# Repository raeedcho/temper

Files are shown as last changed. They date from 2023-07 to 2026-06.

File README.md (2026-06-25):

# temper

This is a split, wireless-only mechanical keyboard fashioned after the [chocofi keyboard](https://github.com/pashutk/chocofi). It started as a simple modification of the original chocofi PCBs to include battery pads and power switches for wireless use, but in the end, I thought there were enough changes to warrant giving it a separate designation. However, this design remains compatible with chocofi cases and plates.

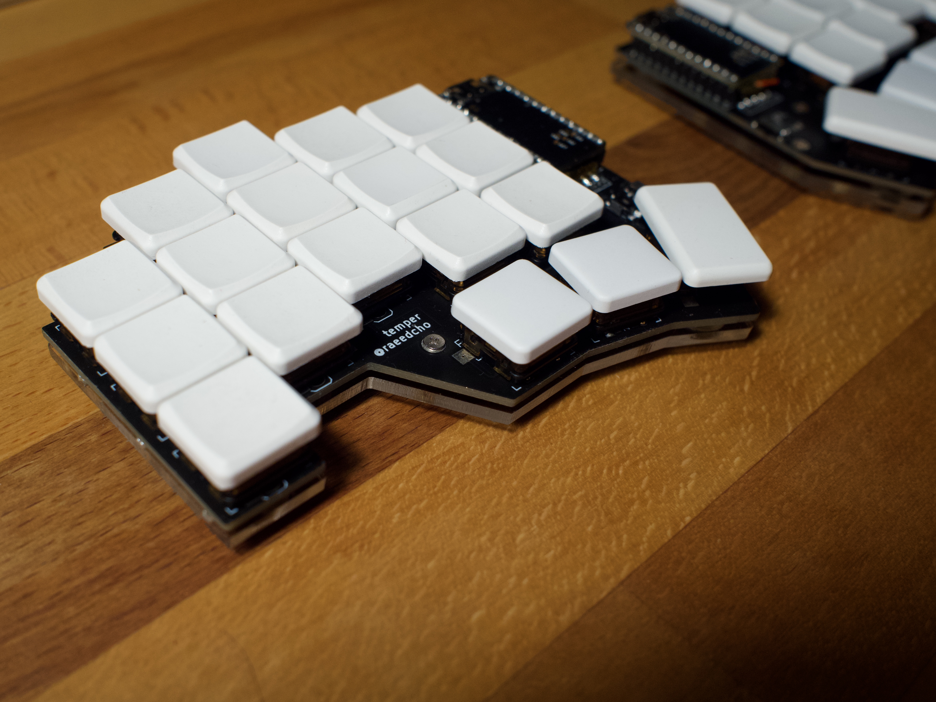
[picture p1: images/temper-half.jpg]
temper keyboard


## Features

- 36-key split keyboard with 3 rows x 5 columns + 3 thumb keys per half 
- Kailh choc spacing
- Sweep-like column stagger (with pinky columns 2 mm lower, like chocofi) with Corne-like thumb cluster
- Reversible PCB (so one design can be used for both halves)
- Kailh choc hotswap sockets
- Intended to be used with [nice!nano](https://nicekeyboards.com/nice-nano)
- Uses 7-pin SPDT power switch and includes pads for battery on keyboard shield PCB
- Support for [nice!view](https://nicekeyboards.com/nice-view)
- Compatible with chocofi cases and plates

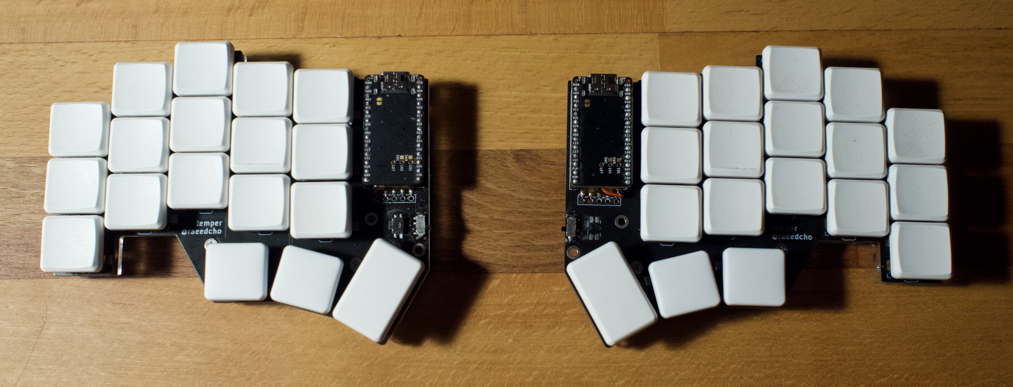
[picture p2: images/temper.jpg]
temper keyboard


## List of changes from original chocofi

- Add power switch
- Add solder pads for battery under ProMicro footprint
- Add footprint for a nice!view screen
- Switch out diode footprints for ones that have solder pads on both sides
- Switch ProMicro footprint for one that uses solder jumpers for cleaner design
- Remove TRRS jack
- Change reset switch out for one I could easily source from [Typeractive](https://www.typeractive.xyz)
- Rework KiCAD schematic for more pleasant development

## Bill of Materials

- 2x PCB (gerber files in [releases](https://github.com/raeedcho/temper/releases))
- 2x nice!nanos
- 2x LiPo batteries (see nice!nano documentation for suggestions)
- 2x Alps miniature SPDT switches
- 2x Panasonic miniature momentary button switches 
- 36x Kailh choc v1 switches
- 36x Kailh choc hotswap sockets
- 36x Choc v1 keycaps
- 36x 1N4148W SMD diodes
- (Technically optional but highly recommended) MCU socket:
  - 4x Mill-Max 310 series machine sockets
  - 48x Mill-Max pins for socketing microcontrollers
- (Optional) Minimal back plate case:
  - 2x 3mm acrylic back plate (SVG file for laser cutting in [case folder](case/temper-bottomplate.svg))
  - 10x M2 4 or 5mm brass standoffs (I used 5mm, but some users have said that 4mm fits better)
  - 20x M2 3mm screws
- (Optional) 2x FR-4 switch plate (goes well with the back plate--gerber files in [releases](https://github.com/raeedcho/temper/releases))
- (Optional) 2x nice!view screens

## Assembly

Assembly of this keyboard requires soldering the jumpers on the front-side of each PCB (underneath the microcontrollers). Past this, the assembly of this keyboard is similar to that of many other split wireless keyboards--there are many guides online to help. In case it helps with assembly, there's a screenshot of the PCB schematic in the somewhat incomplete [PCB folder readme](https://github.com/raeedcho/temper/tree/main/pcb).

Briefly, the full list of steps includes:

- Solder the jumpers underneath where the microcontrollers and battery would go (on PCB front). It's best to do this step first, since it's easiest when there are no other components on the board.
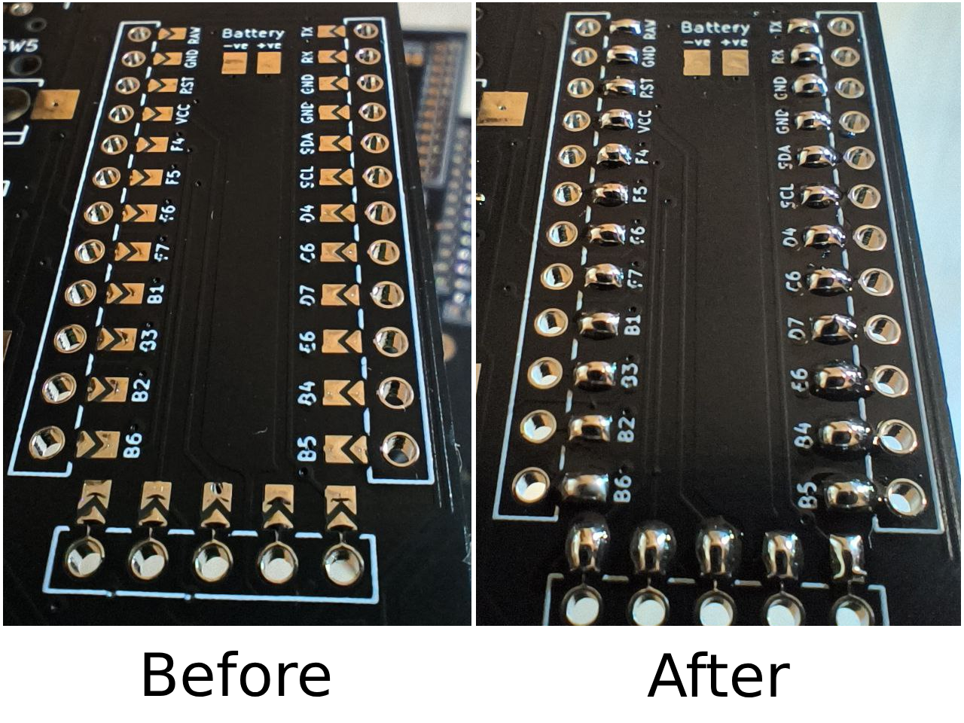
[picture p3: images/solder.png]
Soldered jumpers

- On PCB back:
  - Solder the diodes (ensuring diodes are oriented correctly--check diode schematic to match orientation to PCB)
  - Solder the switch sockets
- On PCB front:
  - Solder reset switch
  - Solder power switch
  - [Socket microcontroller](https://docs.splitkb.com/hc/en-us/articles/360011263059-How-do-I-socket-a-microcontroller-):
    - Solder sockets into PCB
    - Place masking tape (to divert solder from socket for next soldering step)
    - Insert Mill-Max pins or diode legs
    - Place microcontroller (blank side up)
    - Solder pins to microcontroller
    - Carefully remove microcontroller
    - Remove tape
  - (optional) socket nice!view displays (same procedure as socketing microcontroller)
  - *Carefully* solder battery wires to pads (ensuring wires don't short together--I used masking tape to secure wires)
  - Reseat microcontroller
- Putting it all together (follow specific case instructions if applicable)
  - (optional) For back plate:
    - attach standoffs to PCB with screws
    - slide PCB standoffs into the aligned backplate holes
    - secure backplate in place with M2 screws (the backplate will be sandwiched in place between the hot swap sockets and the screw heads)
  - If not using switch plate:
    - press switches directly into PCB sockets (ensuring switch legs make it into the sockets and don't bend out of the way)
  - If using switch plate:
    - press switches into plate
    - align switches with PCB holes and press into sockets (ensuring legs make it into sockets and don't bend out of the way)
  - Place keycaps on switches

## Firmware

This keyboard uses [ZMK firmware](https://zmk.dev), which allows for configuration through GitHub Actions. An example configuration repository is [here](https://github.com/raeedcho/temper-zmk-config.git). The temper has also been added as an outboard on [Miryoku ZMK](https://github.com/manna-harbour/miryoku_zmk) via this [pull request](https://github.com/manna-harbour/miryoku_zmk/pull/42).

## Case options

The temper should be compatible with any case that works on the chocofi. The pictures above show a minimal case using only a laser-cut acrylic backplate (SVG design [here](case/temper-bottomplate.svg)), held on by M2 screws and brass standoffs. It's also possible to add an FR-4 switch plate (KiCAD design [here](case/top-plate)), which helps keep the switches stable in the hot-swap sockets.

Other options:
- The [temper gasket case](https://github.com/calerouxz/TemperKB-case), designed specifically for the temper by [calerouxz](https://github.com/calerouxz). The gasket case is more complex than the simple acrylic backplate and FR-4 switch plate, but has a more polished final look and feel.
- This [custom temper case](https://github.com/AdrianBonpin/zmk-temper), designed by [AdrianBonpin](https://github.com/AdrianBonpin). This repository also contains another example firmware configuration, with support for [ZMK Studio](https://zmk.dev/docs/features/studio).
- A [CNC metal case](https://github.com/CoenTurk/temper-metal), designed by [CoenTurk](https://github.com/CoenTurk). See https://github.com/raeedcho/temper/pull/18 for images.
- A [case with room for a big 600 mAh battery](https://github.com/vdztvboven-cpu/temper-case), designed by [kulderzipke](https://github.com/vdztvboven-cpu).

## Why "temper"?

Tempering is a finicky process that changes the structure of chocolate to make it more shiny, but doesn't really change the taste much.

Likewise, the changes I made to the chocofi didn't alter the original design much, but made some quality-of-life improvements for both development and my own personal aesthetics, at the cost of removing traditional wired operation and possibly making it more difficult to assemble, given the addition of many solder jumpers. 

## Resources

I adapted a few of the elements from these KiCAD libraries for use in this design:

- [chocofi](https://github.com/pashutk/chocofi) - The PCB switch layout came from the original chocofi design
- [kbd](https://github.com/foostan/kbd) - This library, by foostan, the designer of the popular Corne keyboard, provides useful schematic symbols and footprints
- [keyswitches.pretty](https://github.com/daprice/keyswitches.pretty) - library of switch footprints--especially useful for reversible PCBs.
- [swoop](https://github.com/jimmerricks/swoop) - Contains reversible PCB footprints for ProMicro pinout, OLED screens, and 7-pin power switches.

## Similar keyboards

There are many similar keyboards to this one and the chocofi, and I'm sure they've all taken inspiration from each other at one point or another. Here's a (surely incomplete) list:

- [Corne/crkbd](https://github.com/foostan/crkbd) - A popular column stagger, 42-key split keyboard with many variants
- [Cornish Zen](https://lowprokb.ca/collections/keyboards/products/corne-ish-zen) - A low-profile wireless redesign of the Corne with choc spacing, screens, and an aluminum case
- [Kyria](https://splitkb.com/collections/keyboard-kits/products/kyria-rev3-pcb-kit) - Another popular columns stagger, 50-key split keyboard, supporting rotary encoders. MX spacing only, but supports both MX and choc switches. More extreme column stagger on the pinky than the Corne. Large thumb cluster.
- [Ferris](https://github.com/pierrechevalier83/ferris) - Minimalistic 34-key split keyboard borrowing the pinky column stagger of the Kyria. MCU is soldered directly onto the board--not ProMicro pinout compatible.
- [Ferris Sweep](https://github.com/davidphilipbarr/Sweep) - Redesign of the Ferris for ProMicro MCU pinout, which also allows for a diodeless build. Many variations.
- [Swoop](https://github.com/jimmerricks/swoop) - Fork of the Ferris Sweep to add OLED screens and encoders
- [Urchin](https://github.com/duckyb/urchin) - Another fork of the Ferris Sweep to add support for nice!view screens, though with a traditional switch matrix and diodes.
- [Swept Corne](https://github.com/AYM1607/swept-crkbd) - A wireless-only mix between the Corne and Ferris Sweep--basically a choc-spaced Corne with the Kyria pinky stagger (or alternatively a choc-spaced Kyria with a Corne thumb cluster)
- [Phase](https://github.com/mjpauly/phase) - 42-key split keyboard--mix of the original Ferris and Corne.
- [Fifi](https://github.com/raychengy/fifi_split_keeb) - 36-key split keyboard. Basically an MX Ferris Sweep with a Corne thumb cluster
- [Chocofi](https://github.com/pashutk/chocofi) - Choc version of the Fifi. Stagger is like the Kyria and Ferris keyboards, but with the pinky column 2mm lower. The keyboard this repository was based on.
- [Roost](https://github.com/forrestbaer/roost) - Wireless-only Ferris Sweep with an extra thumb key per hand
- [TOTEM](https://github.com/GEIGEIGEIST/TOTEM) - 38 key split keyboard with Sweep-like column stagger. 3 thumb keys, like Corne, but also an extra pinky key. Also designed with finger splay for the ring and pinky fingers.
- [A. Dux](https://github.com/tapioki/cephalopoda/tree/main/Architeuthis%20dux) - 34-key split keyboard with aggressive column stagger and splay
- [KLOR](https://github.com/GEIGEIGEIST/KLOR) - Customizable split keyboard (via versatile break-off PCBs), with on-board MCU, encoders, and OLED screens

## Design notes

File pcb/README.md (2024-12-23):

# temper PCB

This folder houses all of the KiCAD files for the temper PCB.

This PCB is designed to be reversible--this means that it can function as either the left or the right half, depending on which side the assembler solders the jumpers and parts.

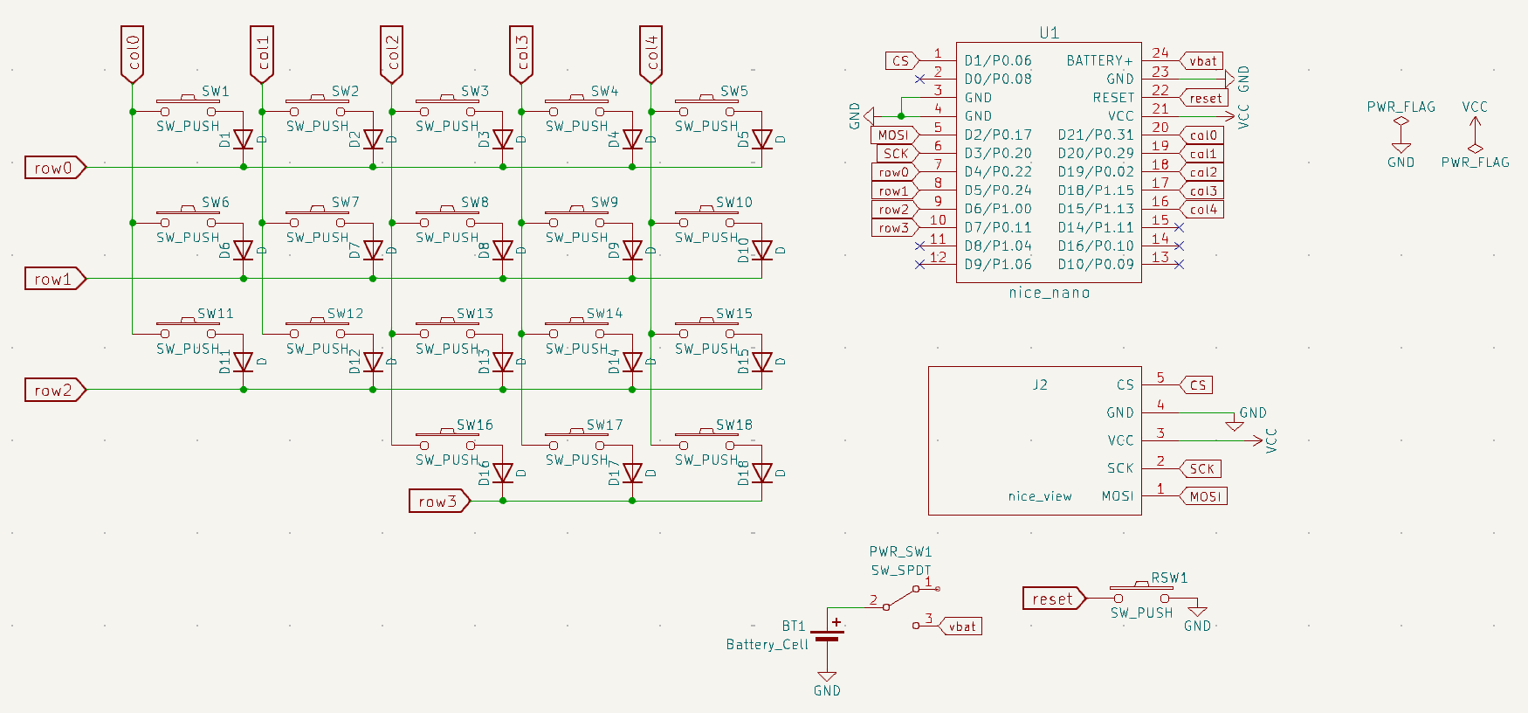
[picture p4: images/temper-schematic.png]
PCB schematic


For this to work, the schematic was designed for one half of the keyboard, as in the image above. Then, I laid out the board using reversible footprints (see resources in [main README](../README.md)).

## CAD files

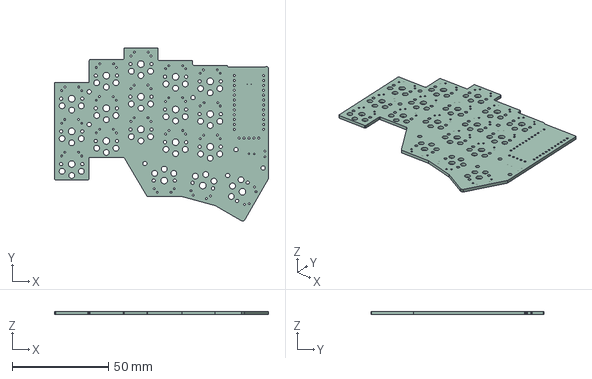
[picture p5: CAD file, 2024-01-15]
pcb/temper.step
111.3 x 90.0 x 1.60 mm

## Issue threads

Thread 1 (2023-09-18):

Mill-Max pins and Panasonic switches part numbers

Ramblurr, 2023-09-18:
Hi there! Building a keyboard for the first time and the temper looks like exactly what I want. Do you have a part/model number for the following components?

* Mill-Max pins
* Panasonic miniature momentary button switches
* Alps miniature SPDT switches

calerouxz, 2023-09-18:
I believe the sockets are Mill-Max 315-43-164-41-001000 which you can find on [digikey](https://www.digikey.com/en/products/detail/mill-max-manufacturing-corp/315-43-164-41-001000/1212142).
And you could use pins 3320-0-00-15-00-00-03-0 which you can also find on [digikey](https://www.digikey.com/en/products/detail/mill-max-manufacturing-corp/3320-0-00-15-00-00-03-0/4147392).

I would also like to know about the switches though.

Ramblurr, 2023-09-18:
> I believe the sockets are Mill-Max 315-43-164-41-001000 which you can find on [digikey](https://www.digikey.com/en/products/detail/mill-max-manufacturing-corp/315-43-164-41-001000/1212142).

@raeedcho mentions Mill-Max 310 sockets.. which I think are part number 310-93-132-41-001000 (don't seem to be available on digikey, but are available at mouser)

Ramblurr, 2023-09-18:
Good to know! Since @raeedcho mentioned 510 by name, it's probably the one to get (with 64 positions).

I researched some other keyboard builds and guess that the Alps SPDT switch might be the [SSSS811101](https://tech.alpsalpine.com/e/products/detail/SSSS811101/) , it seems to be a match to the photo.

Ramblurr, 2023-09-18:
Also the Panasonic momentary switch looks like the [EVQ-PUC02K](https://octopart.com/evq-puc02k-panasonic-41161443?r=sp)

calerouxz, 2023-09-18:
Great to know! I'm pretty much gearing up to build one of these in the near future.

Ramblurr, 2023-09-18:
Ok

> The 310 also seems to have a different contact finish, as it's described as 'tin-lead'

I found another 310 that has 64 positions and no lead: 310-43-164-41-001000

calerouxz, 2023-09-18:
Seems correct. The 310 seems to have longer tails, and is probably considered the 'standard' tail socket according to mill-max's website.
The 315 would probably be a good option if paired with pin headers. This is probably the pairing Typeractive seems to sell as 'ex-solder' sockets and headers.

raeedcho, 2023-09-18:
I sourced many of my parts from [Typeractive](https://typeractive.xyz/collections/parts). There should be information and data sheets there for most of the things.

Specifically:
- Alps SPDT switches part number [SSSS811101](https://cdn.shopify.com/s/files/1/0618/5674/3655/files/ALPS-SSSS811101.pdf?v=1670451309)
- Panasonic momentary switches part number [EVQPUL](https://cdn.shopify.com/s/files/1/0618/5674/3655/files/PANASONIC-EVQPUC02K.pdf?v=1670451309)
- Mill Max pins/sockets I'm not 100% sure of the part numbers, but I got them from [here](https://typeractive.xyz/products/machine-sockets-and-pins)

Hopefully that clears up the confusion, but let me know if it doesn't.

Ramblurr, 2023-09-18:
thanks @raeedcho that clears up a lot!

I've never worked with kicad project files before when printing PCBs (you've got a real nub on your hands sorry). Is there anything else necessary besides opening the project and doing File > Fabrication Outputs > Gerber to produce an output I can zip up and send to PCBWay?

raeedcho, 2023-09-18:
If you just want the gerbers, I've uploaded them to the releases of this repository [here](https://github.com/raeedcho/temper/releases/tag/pcb-v1.0.0)

Come to think of it, I should probably put that in the documentation for others who might have missed that.

triple1c86, 2023-12-12:
Hi, does the keyboard work without the reset button? I have soldered everything including the battery except reset button and nano view. I have also flashed your temper firmware on left split keyboard. I have seen the usb device detected on my arch linux computer as OpenMoko. Inc. Temper, however none of the keys work..

I have made a wired corne keyboard and flashed with qmk. However, I'm quite new with zmk firmware, so I wonder if there's anything that I can troubleshoot this with.. Sorry if this is not the right place to ask about this, however I'll appreciate it if someone can point me the right directions to this.. Tyvm.

raeedcho, 2023-12-12:
The keyboard should work without the reset button (assuming you short the reset pins to flash the boards). I'm not sure what the OpenMoko. Inc. Temper is about--this may be soldering issue or a ZMK firmware issue, I think. Perhaps double check the ZMK firmware settings and look for support in the ZMK GitHub repo or Discord server.

By the way, this thread you've commented in is an unrelated closed issue--it's not a problem, but if you have more questions on this for me, I would appreciate it if you opened a new GitHub issue specifically tailored to this.

Good luck!

Closed 2023-09-18.

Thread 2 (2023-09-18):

About securing the bottom plate

purefall0624, 2023-09-18:
Hello! I really loves the minimalist design of your keyboard. But I'm wondering how to secure the pcb with the bottom plate, you know, about the models of the screws and maybe existing studs. Love from China!

raeedcho, 2023-09-18:
Thanks! As I've built it in the pictures, I just used M2 screws and spacers. The screws are 3mm M2 screws, and they're attached to 5mm brass M2 spacers (also known as standoffs sometimes I think) through the PCB. The bottom plate slides over the spacers on the bottom of the PCB and secures to the spacers with the same 3mm M2 screws.

I'd love to see the result if you end up building one!

raeedcho, 2023-09-18:
I realized that I didn't put this information in the README before--it's there now. Feel free to reopen the issue if you have more questions!

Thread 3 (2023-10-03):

JST Battery Connector?

calerouxz, 2023-10-03:
Is it possible to use a JST battery connectors like these [typeractive JST connector](https://typeractive.xyz/products/battery-jack) or [the one included with the batteries with connectors](https://typeractive.xyz/products/lithium-battery-110mah?variant=43294731665639) with the current design? Or maybe the pads for the connector could be added in the future?

raeedcho, 2023-10-03:
You can definitely use the pigtail connector with the current pad design--you just have to solder the wires into the right spots.

The current design doesn't support the board-mounted JST connector, and I'm not currently planning on adding those pads, though that could change. I had initially wanted to use the board-mounted connector you linked, but found it slightly difficult to make space on the board for it alongside the power and reset switches. I ended up deciding that it would be easy enough to clip or desolder the battery if I ever needed to replace it, but I definitely see the advantages of having the connector.

calerouxz, 2023-10-03:
I was thinking the pigtail connector could work, I'm a bit worried that it could be too long, making packaging the battery difficult on the board, might be something worth trying regardless.

Closed 2023-10-03.

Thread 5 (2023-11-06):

Bottom case dimensions

tmcdonell, 2023-11-06:
Hi! Thanks for creating and releasing this board!

I need to order the bottom plate, but when I upload the design to my local cutting service (I tried two) they estimate that the final board will be about 83mm x 67 mm, which is quite a bit smaller than the PCB so doesn't seem right...

I had to convert the .svg to either .pdf or .dxf for these services and used inkscape to do that, which is perhaps where it is going wrong. Do you have any suggestions, or have the file in another format already that I can try? (.ai is also accepted)

raeedcho, 2023-11-08:
Hmm, I'm not sure why Inkscape would change the scaling, but I guess I've also never used Inkscape, so I can't really comment. I tried exporting a DXF from Illustrator, but it seemed to be blank. I can upload a PDF version here though:

[temper-bottomplate.pdf](https://github.com/raeedcho/temper/files/13298602/temper-bottomplate.pdf)

Let me know if this works for you!

tmcdonell, 2023-11-09:
Thanks, that seems to have worked! :D Size of the design is now reported as 111 x 90mm. Ordered and should be here in a week or so.

Closed 2023-11-09.

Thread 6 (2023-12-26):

Question about: Solder the jumpers underneath the microcontrollers

triple1c86, 2023-12-26:
Hi, just a question about Solder the jumpers underneath the microcontrollers part:

1. do you mean have to solder some tin on the red circle spot shown in the picture?

then another question is if i want to rule out battery issue, can i just solder a wire on the green circle spot?

I be kindly appreciated if you can help a noob like myself out. Thank you.

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

raeedcho, 2023-12-26:
Yes, soldering that jumper you circled basically means that you need to electrically connect the two pads with solder.

As for the battery pads, definitely don't connect those--it could result in a short in the microcontroller.

I'm not sure what you mean by ruling out a battery issue--what issue are you having? You can power the microcontroller without the battery connected by plugging it in to usb, if you want to test your firmware before hooking up the battery.

triple1c86, 2023-12-26:
omg.. wondered what went wrong when none of the buttons work after hours and hours of resoldering this and that, thinking it was my poor soldering skills.. So I revisited your instructions again, only to realise that I read this before and thought its something not important and skipped it.. silly me. thanks for clarifying that.

the battery part was my desparate attempt to fix the none of buttons work issue that I thought its related to..

Most likely thats the solution for me. Thank you very much mate. Ya the best! @raeedcho and thanks for such a wonderful wireless keyboard design!

Closed 2023-12-26.

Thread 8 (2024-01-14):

STEP file for case design

calerouxz, 2024-01-14:
Hi,

Would it be possible to get STEP files to be able to design a 3D-printable case specifically for the Temper? I'd like to include something to better handle the on/off switch among other things.

raeedcho, 2024-01-14:
I'm not sure how to generate STEP files for this, to be honest--if you know how, I'd be happy to add them to the repository.

For the most part, the case files for the original chocofi will basically work for the temper as well, though--that might be a good starting place, if you're willing to give it a go.

calerouxz, 2024-01-14:
I'm currently using a Chocofi case on my temper, but the case design in general could use a bit of refinement, I would also like to try my hand at making an easier rocker for the on/off switch, some tenting options, as well as some nice covers for the nice!nano. Unfortunately I couldn't find a .step file in the Chocofi repo either, but I'd still prefer to start from the temper's, as that would give me an accurate placement for the components.

[Here](https://www.pcbway.com/blog/PCB_Design_Tutorial/How_to_export_a_PCB__step__from_KICAD_to_Fusion_360.html) is a tutorial from PCBWay on how to export to a .step file.

raeedcho, 2024-01-15:
I gave it a shot through KiCAD, and I'm putting the file at this link for now--is this what you're after? https://autode.sk/4aUPt1M

As far as I can tell, this is just a STEP file for the PCB by itself, but doesn't have any of the components on it (since it's a reversible board, I'm not sure how I would put the components on it correctly anyway).

calerouxz, 2024-01-15:
This is exactly what I'm after! The components are not particularly important for what I need them for. This just allows me to have an accurate representation of the board while creating the case.

Thank you very much!

raeedcho, 2024-01-15:
Great! Good luck with the case, I'd love to see it when it's done 😁

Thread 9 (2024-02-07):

Spare boards?

pashashocky, 2024-02-07:
I'm quite tempted to build this, but I've never had to order a custom pcb made.
Wondering if you have any spare PCB's left over or I'll have to explore how to manufacture one :) I guess I can't manufacture one, I'll have to manufacture 5 hah

Happy to buy + pay shipping..?

pashashocky, 2024-02-07:
Ah nvm, JLCPCB is like 10$...

Closed 2024-02-07.

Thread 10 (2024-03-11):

Troubleshooting battery and PCB

keithadams, 2024-03-11:
I'm at the final stage of building a temper and I can't seem to get the battery working on the PCB. I soldered the battery to the PCB and the nice!nano v2 doesn't power on. The nice!nano v2 works when I connect the battery directly to it and the keyboard works, but obviously the power switch can't be used. Any ideas on how I can troubleshoot and isolate the problem? Thanks!

calerouxz, 2024-03-11:
Is it possible to see how you soldered the nicd nano and the battery?

keithadams, 2024-03-12:
I ended up desoldering the battery to test it directly connected to the nice!nano. I had the wires connected like this and I was careful not to accidentally bridge the two terminals.

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

When I connected it directly, the battery worked immediately. Does that rule out the battery as a problem? I charged the battery to 100% and tried again with the PCB, but only using heat resistant tape. I was holding off on soldering again until I narrowed down the issue but I'm willing to re-solder. Just trying to figure out the best way to proceed.

raeedcho, 2024-03-13:
Do you have a picture of your actual board? It's possible there's something else wrong that would be easier to see in a picture. For example, have you soldered the jumpers on the correct side of the PCB?

keithadams, 2024-03-13:
Yes, here's the board as it is now. Also, I have a multimeter available to test.

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

raeedcho, 2024-03-14:
Thanks for the picture. Have you tested with the multimeter to see whether the battery terminal pads are connected to the correct socket pins? Check the [nice!nano pinout](https://nicekeyboards.com/docs/nice-nano/pinout-schematic/ for reference, and make sure the power switch is in the "on" state when you check, since the power switch disconnects the battery from the microcontroller.

If it's not connected, check the connection through the power switch pads. The positive pad should be routed to one of the pads on the power switch, and the socket pin corresponding to battery power should be routed to a different power switch pad.

keithadams, 2024-03-25:
Thanks for the replies! I ordered a new battery just to be safe and soldered it to the PCB. Next, I tried to do a continuity test with a multimeter. Please let me know if I did it incorrectly.

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

When I connect 1 and 2, there is no beep. The power switch is set to "on".

When I connect 1 and 3, there is a beep, regardless of when the switch is "on" or "off".

raeedcho, 2024-03-25:
Have you tried testing the connection between the pin or pad labeled 2 to the top of the three pads to the left of the power switch? I believe these two should be connected regardless of switch state.

If that connection is not good, then it may be the case that the jumper you soldered on the top is not fully connected (it kind of looks like it from the picture). Test whether the pin you indicated as 2 is connected to the blob of solder labeled "RAW" right next to it.

If the connection from the RAW pin to the power switch is fine, then maybe test whether the top two pads on the left of the power switch are connected when the switch is on and not connected when it's off.

keithadams, 2024-04-02:
The toggle switch was the problem and I was able to fix the issue.

First, I used an extra PCB to do a continuity test with an unsoldered toggle switch and found the switch is a little finicky. It works best when pressure is applied towards the PCB. I decided to remove the switch on my board but unfortunately a pad came off in the process. I started fresh with a new board, but this time I started with the power switch. Here's the process that helped me:

1. Place the toggle switch in position and apply pressure towards the board with tweezers.
2. Solder a **single** pin first, and then test for continuity. This means connecting to the positive battery terminal and the RAW pad closer to the battery terminal pads.
3. If there is no continuity, then try again by heating up the solder joint and re-seating the toggle switch.
4. Once it works, solder the rest of the pins on the toggle switch.

Thanks again for the guidance!

Closed 2024-04-02.

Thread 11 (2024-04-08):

Case designed and available

calerouxz, 2024-04-08:
@raeedcho , I know it's been over 2 months since I asked for the PCB model, but I've finally been able to create the case. I'm not done with the documentation just yet and it's missing the real life images, but here's the github repo I've set up for it in case you'd like to link it: [Temper gasket case](https://github.com/calerouxz/TemperKB-case)

I made a post on reddit with an image that you can view: [reddit post](https://www.reddit.com/r/ErgoMechKeyboards/comments/1byyiem/i_was_finally_able_to_finish_this_case_for_my/)

Edit: There are now pictures on the repo for the case.

I should also mention that the temper has been incorporated as an outboard in [Miryoku ZMK](https://github.com/manna-harbour/miryoku_zmk) with [this PR](https://github.com/manna-harbour/miryoku_zmk/pull/42) and can be used to flash the firmware.

raeedcho, 2024-04-10:
Wonderful! I'm out of town at the moment, but I'll add links in the readme when I get a chance. Good work!

raeedcho, 2024-04-13:
Added some links to the readme. Thanks!

Closed 2024-04-13.

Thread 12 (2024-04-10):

Diodeless?

ThomasAlban, 2024-04-10:
Is there any way this could be modified to be diodeless? I'm definitely not an expert, but it seems like there would be few enough keys on each side for there to be 1 GPIO per key (correct me if I'm wrong!)

calerouxz, 2024-04-12:
I took a look at the schematic. I'm pretty sure the nice!view is taking some of the pin on the nice!nano, so there's no longer enough available pins to run all 18 switches per side without diodes.

raeedcho, 2024-04-13:
Ah, yes, I couldn't remember before, but I think that's the reason I didn't make it diode-less. It could be possible to make another version of the temper without the diodes or the nice!view (or the sockets, for that matter) for a very minimal build, but it's not on my radar at the moment.

ThomasAlban, 2024-04-13:
Ah ok makes sense. I might have a go at making this at some point, as I've been wanting to learn more about this anyway. Thanks for your help!

Closed 2024-04-13.

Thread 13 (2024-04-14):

Soldering the jumpers - front or back

paradoxicator, 2024-04-14:
Hello - thank you for your excellent work!  I just wanted to clarify the jumpers - I wasn't understanding if the jumpers needed to be soldered on the front or back of the PCB..

I have completed the whole build, but I soldered it on the back (instead of the battery/front side).  After looking at some pictures of prior questions/issue posts, I noticed that there was a picture of the jumpers soldered on the front side.

Please forgive this newbie if this is a stupid question.  I have never built one with jumpers like this before.

raeedcho, 2024-04-16:
Hi! The jumpers need to be soldered on the front side, under the battery. In hindsight, I probably should have designed it the other way, but that's how it is.

If you've already soldered the jumpers but haven't done the rest, there are a few easy fixes that I think might work:

- First, if nothing else is done, then just flip the PCBs around--they're mirror images, so there's no problem
- If you haven't socketed the microcontroller yet, I believe you can socket that "upside-down", if you're okay with that. The downside is that if you then move to another keyboard and use the same microcontroller, you might have to be aware of how to connect things.
- If things are all soldered, you might have no choice but to desolder some things. If you've never desoldered anything before, I suggest getting some braided solder wick and watching some YouTube videos on desoldering.

Good luck!

KastenTaco, 2024-04-16:
Please make adjust the build instructions accordingly.

paradoxicator, 2024-04-16:
I actually completed everything before I realized this.. I soldered it on the correct side and desoldered the back with a solder wick.  Thank you for the clarification!  It's a great board!

AngryTacoEater, 2024-04-16:
It's great indeed! Didn't mean to sound snarky. Just frustrating when this happens. Would be a shame if others have this happen. The Nice!Nano is pricy to burn up.

raeedcho, 2024-04-17:
The instructions are in the readme already--the first instruction actually:

> - Solder the jumpers underneath the microcontrollers

I could see how this could be easily missed though, since it's not part of the "front" or "back" list of things to do.

Closed 2024-04-17.

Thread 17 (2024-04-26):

Building Miryoku does not work

Zoltan-Balazs, 2024-04-26:
Whenever I try to build the Miryoku firmware, it does not work, see: [https://github.com/Zoltan-Balazs/miryoku_zmk/actions/runs/8844616666](https://github.com/Zoltan-Balazs/miryoku_zmk/actions/runs/8844616666)

I see that the Temper was added like the Corne to the Miryoku repository; building that in the exact same way, just changing `temper` to `corne` in the shield section is successful: [https://github.com/Zoltan-Balazs/miryoku_zmk/actions/runs/8844680219](https://github.com/Zoltan-Balazs/miryoku_zmk/actions/runs/8844680219)

calerouxz, 2024-04-26:
Try building both sides on separate runs. If I remember correctly, building them together resulted in errors for me.

Zoltan-Balazs, 2024-04-30:
Thank you, unfortunately the build still fails with `Error: Keymap found but shield not found. Board used for shield.`
It seems like the workflow does not recognise `temper_right` or `temper_left` as valid shields

calerouxz, 2024-04-30:
I'll try a build later today and report back.

calerouxz, 2024-05-01:
This didn't build for me today either, it may be worth raising a discussion, as I can't see missing or otherwise missing information on the files.

calerouxz, 2024-05-02:
Update on this matter! I found the issue and why the build for the temper was broken on Miryoku. I'll keep this documented here for posterity and I'll try posting a PR to Miryoku ZMK.
The outboard refs for temper needed to be updated, as [this commit](https://github.com/raeedcho/temper-zmk-config/commit/024290005a9ae565d3afd7ad716056e3e9947976) moved the files on the temper's repository and Miryoku outboards require the refs to build. I've opened [this PR](https://github.com/manna-harbour/miryoku_zmk/pull/51) to fix it in Miryoku ZMK.

raeedcho, 2024-05-02:
Ah yes, I had to move the files to comply with the new Zephyr update but didn't realize it would break the Miryoku build. Thanks for looking into and fixing it!

calerouxz, 2024-05-03:
The PR regarding the temper has been merged into Miryoku. I tested a build (and flashed) and it now works correctly. Manna also made a sample build which also compiled. @Zoltan-Balazs you can sync your fork and it should now work.

Zoltan-Balazs, 2024-05-06:
Thank you, it works as intended, I was able to verify on my own fork as well!
I don't think I would've been able to figure this out, thank you @calerouxz :smile:

Closed 2024-05-06.

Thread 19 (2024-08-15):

Reset switches hard to source

ThomasAlban, 2024-08-15:
Hi,
It’s practically impossible for me (uk) to source the reset button which is used on this keyboard without paying extortionate shipping. The one on the original chocofi (pts636) is much more easily available. Is there any chance of a version of this keyboard being made that supports that type of reset switch?
Thanks

raeedcho, 2024-08-16:
Ah, that is frustrating--I didn't realize that when designing the board. Unfortunately, I don't currently have plans to make a second version of the temper, but I wouldn't rule it out, if there are enough desired changes to make it worthwhile. Sorry! I'll leave this issue open for now as a feature request and let others comment.

ThomasAlban, 2024-08-16:
Yeah that would be great.
I'm really keen to build the temper as it seems like pretty much my ideal keyboard (I currently use a corne but I don't need the outer row of keys and I find the little finger stagger not low enough)
When I build it I'd like to add 1000mah batteries below the keyboard, so if I solder the battery connectors to the pads on the bottom of the pcb would it still work? (So I don't have to have wires protruding out of the keyboard)
If not, perhaps another modification could be a little indent above the battery pads so the wires can wrap around without protruding.

raeedcho, 2024-08-17:
Yes, you should be able to just solder the batteries onto the backside of the board. I would double check with a multimeter to make sure, but the PCB is designed so that the pads on front and back are directly connected.

AdrianBonpin, 2024-12-31:
Quick question, regarding the reset switch as I'm not proficient with reading pcbs (which I need to really learn). Will standard 4 pin reset switches work? Specifically these ones that I can source.
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

I apologize if my question has a simple answer or may be mistaken and I thank you in advance. (And an advanced Happy New Year)

raeedcho, 2025-01-02:
I'm sorry to say that I'm not sure this will fit in the same reset switch spot--it kind of looks like the contacts are not quite positioned correctly to sit on the PCB pads, but I can't be certain.

AdrianBonpin, 2025-01-03:
Footprint aside as I can simply play around with the placement, does it function the same? but just with 4 pads?

I was trying to trace where the 4 pads lead to but I really couldn't figure it out. Thanks again

anycancellable, 2025-05-13:
Hey,
I just finished building (thanks @raeedcho) using a switch from [Aliexpress](https://vi.aliexpress.com/item/1005002845025014.html) (1005002845025014 item id).

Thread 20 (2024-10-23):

Just to say: Thank you !!

jfaixo, 2024-10-23:
I recently fell into the rabbit hole of the "diy keyboard" community, and picked your great design as a first keyboard to build :)

That went extremely well, "just" working from the first time! Dropping some pictures: https://imgur.com/a/s8EuhC4

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

Some little points that maybe could be better explained in the repository:

- PCB & electronic:
  - As I'm rather new (especially into electronics), I never saw a reversible PCB before. I had to look into kicad to understand how and on which side the triangle jumpers must be soldered. A word in the readme explaining that these jumpers must be soldered correctly depending on how the MCU will be oriented would be great!
  - everything went extremely smoothly, I followed [this guide](https://github.com/rafaeldelboni/buildlogs/blob/main/crkbd-choc-spaced-switch.md)
- case: usually there is a lot of focus on the electronic part, but little on the housing, and this is where I had a harder time to figure how to do it before ordering the parts
  - One trap I fell into (happily without consequence) is about the thickness of the switch plate. I just did not think to check before ordering. I used PCB based switch plates (the blue ones in the pictures), and ordered them with the default settings of jlcpcb. But the default PCB thickness is 1.6mm, and the thickness for Kailh choc switches to properly clip is...1.2mm. In the end this is not an issue, as the switches are already well engaged en the switch plate + also properly maintained by the PCB holes underneath. In the end there is no moving part at all, as everything is tightly engaged (even though I chose not to screw the switch plate. Screws are below it, completely hidden)
  - an other minor trap is that I did not see the option (enabled by default) that add a fabrication identifier on PCBs. For the switch plate this is a bit sad, as there is an undesired id visible on one of the two splits... (here again lucky me: choc spacing is very tight, this is almost invisible)
  - something I managed to figure out beforehand but is not explicited in the repository: the holes in the bottom plate provided have a diameter of 3.2mm, so normal M2 screws would pass through these holes... I chose to use screw inserts melted into the plexiglass. Also: I had to add a scale as a legend in the svg so that my local supplier can be sure of the dimensions of the end product

As a conclusion: THANK YOU VERY MUCH for the design! And if you wish I can push a PR to add the previous build details :)

raeedcho, 2024-10-25:
Nice, looks really great! I'm glad you were able to figure everything out. And thanks for the comments--I'll try to clarify things in the readme a bit more.

Just to clarify a few things:
- Regarding the jumper solder locations, the readme states to solder the jumpers on the front side of the PCB, directly under the microcontrollers. How should I reword this to clarify?
- That's strange about the bottom plate holes being too big for your M2 screws--they seemed to work totally fine for me. Which M2 screws did you use?

Thanks again for the constructive feedback! Hope you enjoy the new keyboard!

jfaixo, 2024-10-26:
> * Regarding the jumper solder locations, the readme states to solder the jumpers on the front side of the PCB, directly under the microcontrollers. How should I reword this to clarify?
Ok no sorry that's just me that did not carefully read everything... my bad ! (having to dig in to understand was also enjoyable !)

> * That's strange about the bottom plate holes being too big for your M2 screws--they seemed to work totally fine for me. Which M2 screws did you use?

I used:
- these inserts (M2 OD 3.5mm variant): https://fr.aliexpress.com/item/1005003582355741.html melted into plexiglass (3mm plexi)
- these spacers (2mm): https://fr.aliexpress.com/item/1005003068856952.html (because kailh hotswaps are 1.8mm tall)
- these (very standard) M.2 screws: https://fr.aliexpress.com/item/4000310491280.html in their 6mm variant

So: pcb 1.6mm + 2mm spacers + 3mm insert ~= 7mm, the M.2 screws nicely hold the whole thing :)

raeedcho, 2024-10-27:
I may not have totally understood your last comment about the backplate holes being too big--do you mean that the heads of the M2 screws would go through the holes? Or that the brass spacers I suggested in the repository would slide through?

If it's the latter, then I intentionally designed it so that the backplate would slide onto the spacers screwed onto the PCB. This means that the backplate isn't actually secured in place, though in practice, if the spacers are short enough, the plate is sandwiched quite well between the M2 screws heads and the sockets on the PCB, and it doesn't slide around.

If it's the former, I'm surprised because the M2 screws that I and others have used seem to have been the right size not to slip through and do indeed hold the backplate to the PCB. Though it's possible that not all M2 screws would work the same way.

Either way, I'm glad you found a good solution to the problem!

jfaixo, 2024-10-30:
Yes it is the latter option, standard M2 spacers just fit in the hole, so this is by design :) But my M2 screw heads barely grab the border of the hole (it's submillimetric). In the end I am very happy with the inserts melted in the backplate, it feels strong :muscle:

Your project inspired me, I might create a variation of it in 2025, for a more fixed setup, with underglow, bigger batteries, and a thumb cluster more fit to my hands (I have thin long fingers, I cannot reach the innermost thumb keys, without having to move away my palm).

Thanks again !

gurland, 2024-10-30:
Hello, @raeedcho, I`d like to address this:
>     * Regarding the jumper solder locations, the readme states to solder the jumpers on the front side of the PCB, directly under the microcontrollers. How should I reword this to clarify?

It was my first keyboard building experience and this step was not obvious at all. I spent a lot of time digging issues on GH and gerber file to understand what are these "jumpers".

So I`ve opened a PR #21 that clarifies what needs to be done in the picture

raeedcho, 2024-10-30:
Got it--thanks for the feedback and the PR!

@jfaixo Wonderful! Feel free to send me a link if and when you make your variation 😁

gurland, 2024-10-31:
@jfaixo could you please provde the svg file with the scale?

jfaixo, 2024-10-31:
Just created https://github.com/raeedcho/temper/pull/22 if you wish the scale as a first step.

But having it with "true" width/height information would be better I think. Like have 1 pixel == 1mm or 0.1mm and a proper width/height tagging seems to be the way.

raeedcho, 2024-10-31:
Ah, I think I misunderstood the initial problem with the SVG then. I didn't realize the scale wasn't already embedded in the SVG--when I open the file on Adobe Illustrator, it seems to have the scale correct. And when I sent the file to the laser cutter, it just sort of worked perfectly.

To clarify, @gurland, are you saying that the scale info that your manufacturer had when opening the file is wrong?

jfaixo, 2024-10-31:
Yes that was my issue: the first cost estimation I did with the original svg was not OK (hole size was 5.76mm according to their scaling interpretation).

gurland, 2024-10-31:
> To clarify, @gurland, are you saying that the scale info that your manufacturer had when opening the file is wrong?

Yes, after opening the original SVG file in their software it displayed 83.45mm X 67.493mm

raeedcho, 2024-11-06:
That's very strange--I tried uploading the file to [Ponoko](https://ponoko.com), and there, it says the file is 111.27 mm x 89.92 mm (see image).

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

What vendors did you two use? I'm wondering if maybe different vendors use different indicators for SVG sizing.

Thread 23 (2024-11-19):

Why solder jumpers?

hitchclimber, 2024-11-19:
Hi, sorry this is not a real issue, but there was no tab to start a discussion. I'm not an electrical engineer and new to soldering and was wondering why do we have to solder the jumpers? Is that some standard practice in that case?
In the example pictures it doesn't look like soldering them creates any connection.

raeedcho, 2024-11-19:
Soldering them does indeed create a connection--if you look at the before picture, there's a gap between the jumper pads that gets bridged when you solder them. In general solder jumpers allow for modification of the circuit for specific purposes after the PCB has been printed, creating connections where there are not wired connections in the copper traces of the PCB. In this case, the jumpers need to be soldered to complete the connections correctly for the microcontroller to the rest of the board PCB.

Design-wise, there's one main problem the jumpers solve in the temper: I wanted to use a reversible PCB so that I could use the same design for both halves. There are other solutions to this problem:

- put separate holes for the MCU depending on which half it's on (see the chocofi for an example of this solution)
- solder the microcontroller upside down on one of the halves (I don't think I've ever seen this, but it's a possibility I think)
- give up the reversibility and just make separate designs for each half (doubles the price of PCBs)

I felt like the jumpers were the more elegant solution, at the price of being slightly more finicky.

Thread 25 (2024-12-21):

Consider marking which microcontroller pins on the board map to which rows/columns

wyrmisis, 2024-12-21:
While building my Temper, I've hit a snag in trying to get my left half, second row keys to fire. In debugging my issue, I've tracked it down to the connection between the microcontroller and the PCB.

In looking around for help on this, I found [SplitKB's docs](https://docs.splitkb.com/troubleshooting/key#an-entire-row-or-column-does-not-output-anything), which shows that the PCBs for their kits note row/column pins with `C#` and `R#`, where `#` is the corresponding number.

I'd find it helpful if, whether as a diagram in the build instructions or on the PCB itself, there were some way to know what pins map to what rows or columns.

(and as an aside, I'd also appreciate if anyone could point me at the pin I ought to be looking for, so I can quadruple-check my amateur soldering job :melting_face: )

raeedcho, 2024-12-23:
Ah, yes, I considered labeling the row and col pins appropriately but that left many MCU pins unlabeled. I thought instead it might make most sense to label the pins how the MCU defined them, trying to give more information about what all the pins were. I'm not sure this was the right idea in hindsight, but that's a problem I can solve for the next one potentially.

In any case, to help you (and any others) out, I dropped a screenshot of the PCB schematic into the repository, which you can see [here in the new PCB folder readme](https://github.com/raeedcho/temper/tree/main/pcb). Hope this helps you out, but let me know first you'd like more information!

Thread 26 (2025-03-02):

struggling to get nice!view working

pashashocky, 2025-03-02:
Trying to get nice!view to work with miryoku, the displays don't currently turn on do I need to do something special?

tried all the below
```
name: 'Build temper nice_nano_v2 nice_view'
on: [push, pull_request, workflow_dispatch]
jobs:
  build:
    uses: ./.github/workflows/main.yml
    secrets: inherit
    with:
      board: '["nice_nano_v2"]'
      shield: '["temper_left nice_view_adapter nice_view","temper_right nice_view_adapter nice_view"]'
      custom_config: '["#define MIRYOKU_ALPHAS_QWERTY\n#define MIRYOKU_EXTRA_COLEMAKDH\n#define MIRYOKU_KLUDGE_MOUSEKEYSPR"]'
      kconfig: '["CONFIG_ZMK_SLEEP=y\nCONFIG_ZMK_MOUSE=y"]'
```

```
name: 'Build temper nice_nano_v2 nice_view'
on: [push, pull_request, workflow_dispatch]
jobs:
  build:
    uses: ./.github/workflows/main.yml
    secrets: inherit
    with:
      board: '["nice_nano_v2"]'
      shield: '["temper_left nice_view","temper_right nice_view"]'
      custom_config: '["#define MIRYOKU_ALPHAS_QWERTY\n#define MIRYOKU_EXTRA_COLEMAKDH\n#define MIRYOKU_KLUDGE_MOUSEKEYSPR"]'
      kconfig: '["CONFIG_ZMK_SLEEP=y\nCONFIG_ZMK_MOUSE=y"]'
```

```
name: 'Build temper nice_nano_v2 nice_view'
on: [push, pull_request, workflow_dispatch]
jobs:
  build:
    uses: ./.github/workflows/main.yml
    secrets: inherit
    with:
      board: '["nice_nano_v2"]'
      shield: '["temper_left nice_view_adapter nice_view","temper_right nice_view_adapter nice_view"]'
      custom_config: '["#define MIRYOKU_ALPHAS_QWERTY\n#define MIRYOKU_EXTRA_COLEMAKDH\n#define MIRYOKU_KLUDGE_MOUSEKEYSPR"]'
      kconfig: '["CONFIG_ZMK_SLEEP=y\nCONFIG_ZMK_MOUSE=y\nCONFIG_ZMK_DISPLAY=y"]'
```

pashashocky, 2025-03-02:
Same issue as here: https://www.reddit.com/r/ErgoMechKeyboards/comments/1fbcnld/need_help_troubleshooting_niceview_displays_not/

Closed 2025-03-03.

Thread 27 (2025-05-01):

Brass spacer

honweng, 2025-05-01:
Hello there, thanks for the awesome board. I have ordered the PCB print but have some doubts on the M2 brass standoff - may I know what is the maximum diameter of the brass standoff that I should be getting?

anycancellable, 2025-05-14:
@honweng Chipping in as I recently finished my build and also went through this question. I ordered my acrylic backplate from 42keebs, and Pete adjusted the file so the hole is ~2.2 mm which was a good fit for M2 screws and M2 female to female Brass standoffs.

honweng, 2025-05-14:
@raeedcho : shouldn't the standoff diameter be bigger than 3.2cm, instead of smaller? A standoff smaller than 3.2cm will cause the back plate to slide through the standoff.

raeedcho, 2025-05-15:
The backplate is actually designed to slide over the standoffs and be secured in place with screws--this leads to a very low profile design.

raeedcho, 2025-05-15:
You are not wrong, but that is exactly how it was designed--the back plate slides on and the screws just fasten to the spacer. The back plate is sandwiched between the screw heads and the PCB (really the hot swap sockets), and in my boards, it doesn't slide along the spacers at all.

raeedcho, 2025-05-15:
> Ah, I didn't know that but I actually really like that idea. Could you specify that in the readme?
>
> I thought the hole is used for the screws to go through. I even used a smaller standoff because with the 4mm standoff recommendation still felt too thick.

Ah, I didn't realize this was confusing--the assembly instructions currently read:

> - (optional) For back plate:
>   - attach standoffs to PCB with screws
>   - slide back plate onto standoffs and secure with screws

Do you have suggestions for how to re-word it?

anycancellable, 2025-05-15:
> (optional) For back plate:
> attach standoffs to PCB with screws
> slide back plate onto standoffs and secure with screws

> Do you have suggestions for how to re-word it?

How about:

- (optional) For back plate:
    - attach standoffs to PCB with screws
    - align the back plate so the standoffs slide into the holes
    - fasten the back plate by screwing into the ends of the standoffs

I think _"into the holes"_ instead of _"onto standoffs"_ reads differently and probably makes it more clear.

raeedcho, 2025-05-19:
Thanks, I've updated the readme with a version of the new suggested language ("into holes" instead of "onto standoffs").

Closed 2025-05-14.

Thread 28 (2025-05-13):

Board/screen doesn't enter idle/deep sleep

anycancellable, 2025-05-13:
Hey!

First of all, thanks @raeedcho for this awesome design, this was my first custom build (and first soldering) and it all turned out great.
I added the optional nice!views and they work, except the keyboard seemingly doesn't enter idle/deep sleep mode.

I didn't fork your config repo because I wanted to see how zmk installer works, but I copied your files to [my repo](https://github.com/anycancellable/zmk-temper).

I'm not sure what's preventing the board to enter idle mode and let the displays turn off.

anycancellable, 2025-05-14:
Out of curiosity I installed a base corne firmware to test it, and both idle and deep sleep works, the keyboard turns off the display and disconnects from bluetooth so I guess either something gets overriden in the config or something is missing compared to corne.

Does your board go to deep sleep without screens?

raeedcho, 2025-05-15:
I believe it does, but I suppose I haven't really tested the deep sleep function in a while (I usually just use the power switches to turn the boards off when I leave my computer or put the keyboards in my bag to take to work).

anycancellable, 2025-05-15:
I actually got it working after countless hours. The key was adding a `.conf` file under `/config`. I'm not exactly sure why this works. I have a different repo [here](https://github.com/anycancellable/zmk-config-temper), but it actually works for both.

This repo that I linked, doesn't have `boards/shields/temper/boards/nice_nano_v2.overlay`. Can you tell me why was it needed for you?

raeedcho, 2025-05-18:
Glad it's working for you now!

> This repo that I linked, doesn't have boards/shields/temper/boards/nice_nano_v2.overlay. Can you tell me why was it needed for you?

I'm not sure I remember why it was necessary before--it could be that I had started with a different version of ZMK possibly?

Closed 2025-05-18.

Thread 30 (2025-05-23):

Help with ordering switch plate and PCB

drderuiter, 2025-05-23:
Hi, I plan on building this keyboard. It will be my very first.

I'm planning on ordering the PCB and switch plate through JLCPCB. It seems that I can just drag and drop the PCB gerber on their website and hit "add to cart". For the switch plate, I'm doing the same since it is also FR-4, but it results in the following:

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

I wonder if that will result in the desired switch plate. I'm not sure what the color differences indicate. Would you able to clarify how (and where) you ordered these parts?

Thanks a lot!

raeedcho, 2025-07-22:
Great, good luck with the build!

Closed 2025-07-22.

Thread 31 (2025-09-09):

Solder Battery on PCB Back

nicobrauchtgit, 2025-09-09:
Hi @raeedcho,

First up, thank you so much for this amazing project! This is my first time building a keyboard and this project is exactly what I was looking for 🙌.

I was wondering: would it be possible to solder the battery to the backside of the PCB (where the diodes and switch sockets are)? If so, which jumpers would I need to solder there?

I have some space underneath the PCB for a bigger battery, and this would make the wire routing smoother.

Thanks a lot!

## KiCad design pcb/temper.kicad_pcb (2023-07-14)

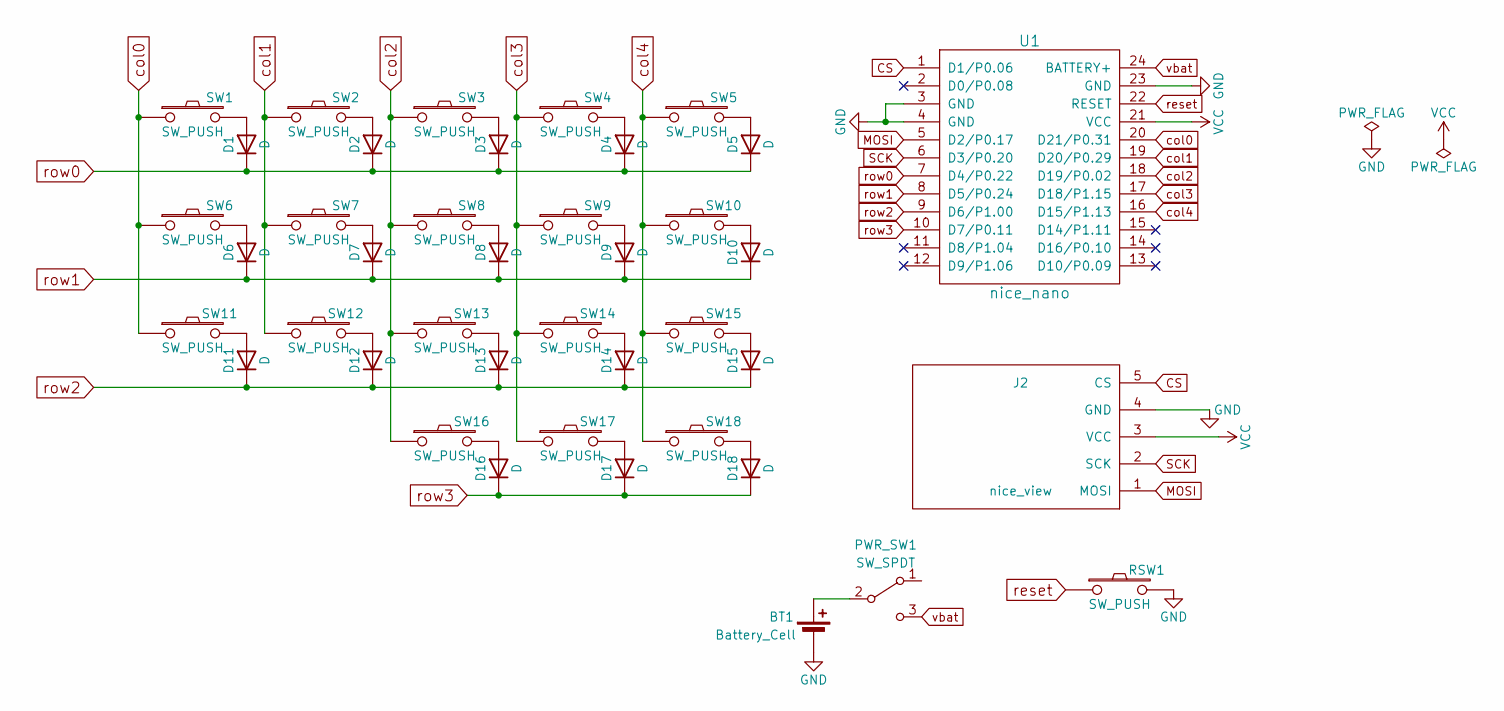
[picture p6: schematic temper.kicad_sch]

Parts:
BT1: Battery_Cell; Battery_pads_reversible
D1, D2, D3, D4, D5, D6, D7, D8, D9, D10, D11, D12, D13, D14, D15, D16, D17, D18: D; D_SMD_TH
J2: nice_view; nice_view_jumpers
PWR_SW1: SW_SPDT; power_switch_padreverse
RSW1: SW_PUSH; Panasonic_EVQPUL_EVQPUC_reversible
SW1, SW2, SW3, SW4, SW5, SW6, SW7, SW8, SW9, SW10, SW11, SW12, SW13, SW14, SW15, SW16, SW17, SW18: SW_PUSH; Kailh_socket_PG1350_reversible
U1: nice_nano; ProMicro_jumpers

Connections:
CS: J2.5 (CS), U1.1 (D1/P0.06)
GND: BT1.2 (-), J2.4 (GND), RSW1.2, U1.3 (GND), U1.4 (GND), U1.23 (GND)
MOSI: J2.1 (MOSI), U1.5 (D2/P0.17)
unnamed: BT1.1 (+), PWR_SW1.2 (B)
unnamed: D1.2 (A), SW1.2
unnamed: D2.2 (A), SW2.2
unnamed: D3.2 (A), SW3.2
unnamed: D4.2 (A), SW4.2
unnamed: D5.2 (A), SW5.2
unnamed: D6.2 (A), SW6.2
unnamed: D7.2 (A), SW7.2
unnamed: D8.2 (A), SW8.2
unnamed: D9.2 (A), SW9.2
unnamed: D10.2 (A), SW10.2
unnamed: D11.2 (A), SW11.2
unnamed: D12.2 (A), SW12.2
unnamed: D13.2 (A), SW13.2
unnamed: D14.2 (A), SW14.2
unnamed: D15.2 (A), SW15.2
unnamed: D16.2 (A), SW16.2
unnamed: D17.2 (A), SW17.2
unnamed: D18.2 (A), SW18.2
SCK: J2.2 (SCK), U1.6 (D3/P0.20)
VCC: J2.3 (VCC), U1.21 (VCC)
col0: SW1.1, SW6.1, SW11.1, U1.20 (D21/P0.31)
col1: SW2.1, SW7.1, SW12.1, U1.19 (D20/P0.29)
col2: SW3.1, SW8.1, SW13.1, SW16.1, U1.18 (D19/P0.02)
col3: SW4.1, SW9.1, SW14.1, SW17.1, U1.17 (D18/P1.15)
col4: SW5.1, SW10.1, SW15.1, SW18.1, U1.16 (D15/P1.13)
reset: RSW1.1, U1.22 (RESET)
row0: D1.1 (K), D2.1 (K), D3.1 (K), D4.1 (K), D5.1 (K), U1.7 (D4/P0.22)
row1: D6.1 (K), D7.1 (K), D8.1 (K), D9.1 (K), D10.1 (K), U1.8 (D5/P0.24)
row2: D11.1 (K), D12.1 (K), D13.1 (K), D14.1 (K), D15.1 (K), U1.9 (D6/P1.00)
row3: D16.1 (K), D17.1 (K), D18.1 (K), U1.10 (D7/P0.11)
vbat: PWR_SW1.3 (C), U1.24 (BATTERY+)

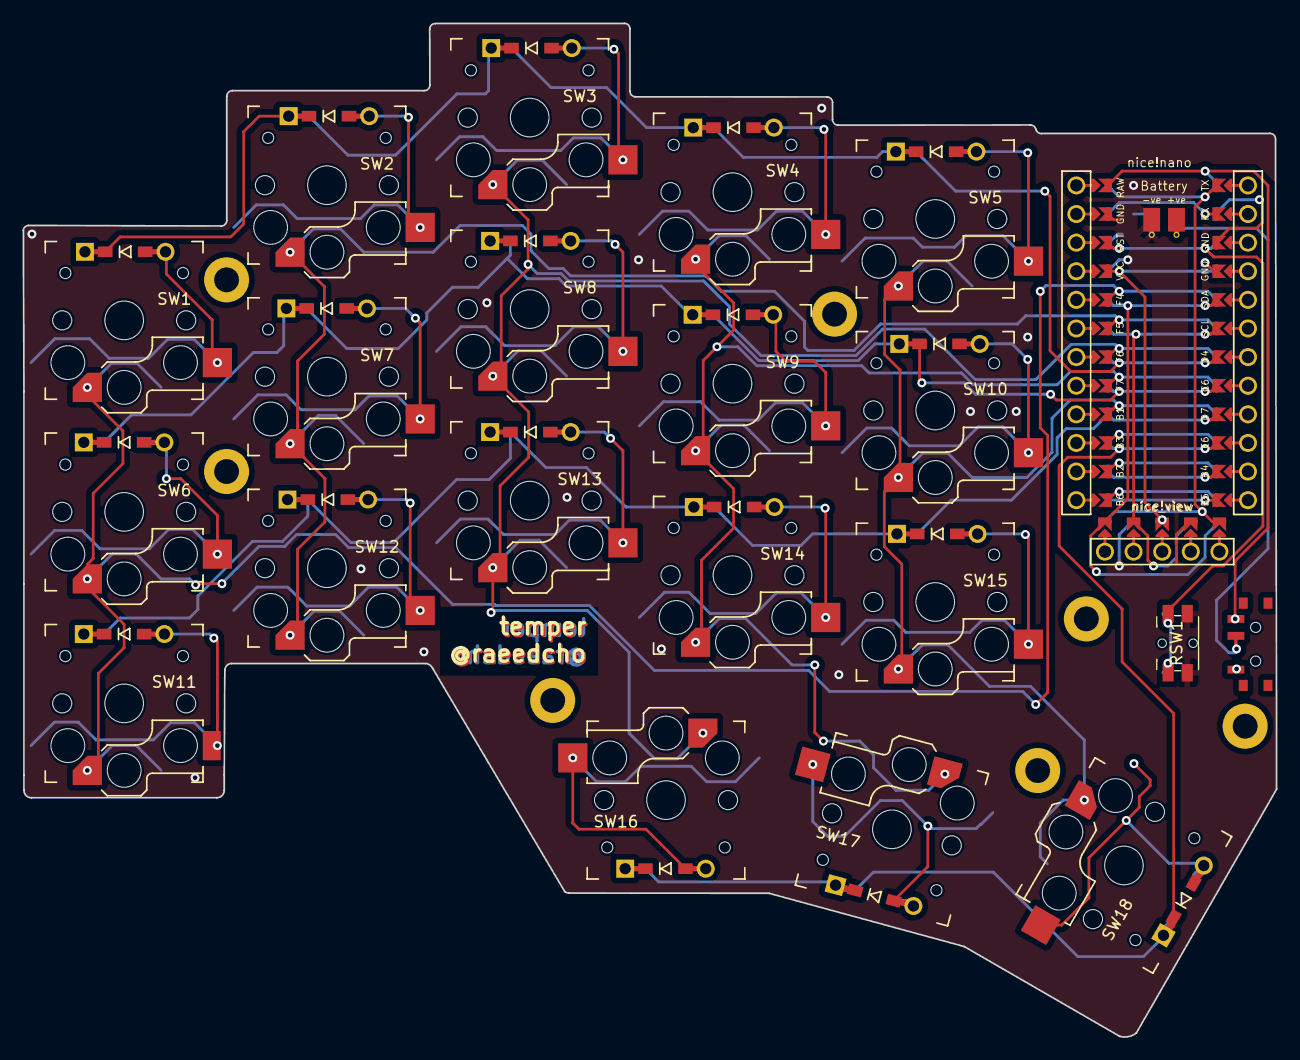
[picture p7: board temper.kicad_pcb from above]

Board: 2 copper layers, 111.3 x 90.0 mm, 48 parts (0 on the bottom side), 35 nets.

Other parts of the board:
H1: h1; LEGO_HOLE
h2: h2; LEGO_HOLE
h3: h3; LEGO_HOLE
h4: h4; LEGO_HOLE
h5: h5; LEGO_HOLE
h6: h6; LEGO_HOLE
h7: h7; LEGO_HOLE

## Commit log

2023-07-07 feat: add kicad-specific gitignore
2023-07-07 feat: add kbd and keyswitches pcb libraries as submodules
2023-07-13 feat: add swoop footprint library
2023-07-13 feat: add dumta schematic, pcb, and other files
    [dumta.kicad_pcb, dumta.kicad_sch]
2023-07-13 feat: add JLCPCB design rules, as best I can tell
    [dumta.kicad_pcb]
2023-07-13 feat: move some footprints over to dumta library
2023-07-13 feat: change footprints and alter them to match design rules
    [dumta.kicad_pcb, dumta.kicad_sch]
2023-07-13 fix: fix all major design rule errors
    [dumta.kicad_pcb]
2023-07-14 refactor: rename kicad project to temper, keeping the library name the same
    [temper.kicad_pcb, temper.kicad_sch]
2023-07-14 feat: change some output settings
    [temper.kicad_pcb]
2023-07-14 fix: add nice!nano and nice!view silkscreen
    [temper.kicad_pcb]
2023-09-06 refactor: move elements of hardware folder to root
    [temper.kicad_pcb, temper.kicad_sch]
2023-09-07 fix: remove duplicate plate from bottom plate SVG
2023-09-18 doc: Update README with info about Gerber releases
2023-09-18 docs: add info about bottom plate SVG file
2023-09-18 doc: add items to BOM and add assembly instructions
2024-01-09 doc: update standoff info in readme
2024-01-15 feat: add STEP file for PCB (for designing cases)
    [temper.step]
2024-04-13 doc: update readme with case and firmware options
    Update from calerouxz: https://github.com/raeedcho/temper/issues/11
2024-04-17 doc: clarify jumper location in README.md
    Clear up ambiguous language in assembly instructions related to which side to solder jumpers
2024-04-17 feat: add PCB schematic for top plate
    [temper-topplate.kicad_pcb]
2024-04-17 fix: save plate modification
    [temper-topplate.kicad_pcb]
2024-04-17 fix: add project file to gitignore (only need pcb file)
2024-04-17 feat: remove useless holes from top plate
    [temper-topplate.kicad_pcb]
2024-04-17 doc: add information about switch plate
2024-10-30 docs: add soldered jumpers image
2024-12-23 doc: add PCB readme and schematic image
2024-12-23 doc: update README.md with link to PCB schematic
2025-05-19 Update README.md with new backplate assembly description
    Remove some confusion on minimal backplate assembly description
2025-10-14 Update README.md with new case option
    Added link to a new user-created case option
2025-11-03 Add CNC metal case option to README
2026-06-25 feat: add a contributed big-battery case option to readme (#33)
    * Update README.md
    * small stylistic update to readme
    ---------
